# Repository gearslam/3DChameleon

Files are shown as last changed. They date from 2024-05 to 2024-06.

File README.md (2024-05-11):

# 3DChameleon
Klipper direct stepper  control for 3DChameleon

Setup for Ender 3 Max Neo, with Sprite Extruder Pro with K1 Hotend, silicone wipe purge bucket, and BTT SKR3 EZ with BTT_MOT_EXP expansion module.
ysplit_distance is configured for custom y-splitter, 2in1 & 4in1 Splitter by Solidoodle2 on Thingiverse: https://www.thingiverse.com/thing:3490163
distance will need to be increased for original 3DChameleon Y-Splitter.

TOOL_INIT there is a configuration value that needs to be adjusted for proper filament selection.

Purge Bucket for CR-10 with adjustable X-Axis by randyre on Thingiverse: https://www.thingiverse.com/thing:4134504
For K1 or volcano nozzle purge wipe bucket needs to be trimmed down about 6mm using negative parts volume in slicer.

PrusaSlicer Start G-code:
START_PRINT EXTRUDER_TEMP={first_layer_temperature[0]} BED_TEMP={first_layer_bed_temperature[0]}
T{initial_tool}  ;only needed for PrusaSlicer, Orca Slicer, uncheck Manual Filament Change.

Filament Change with purge and wipe just under 7 seconds.

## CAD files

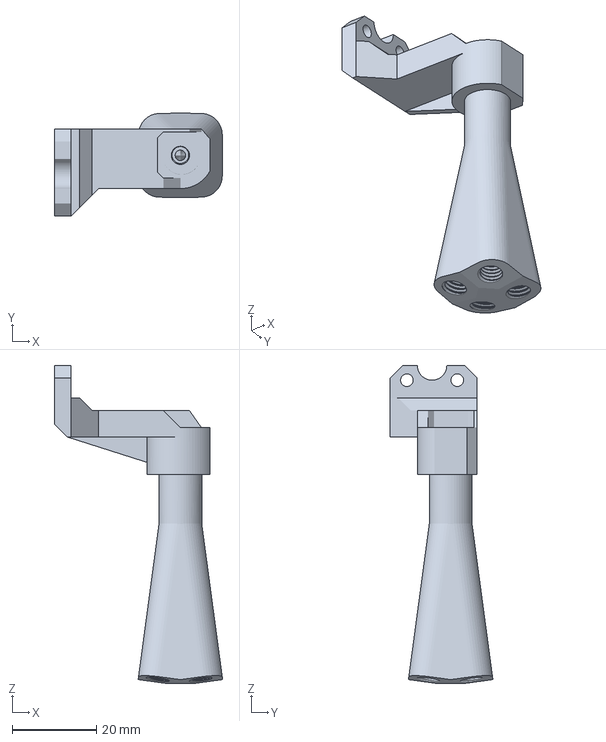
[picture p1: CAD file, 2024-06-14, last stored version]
4in1_thread_modded.3mf
40.1 x 24.5 x 75.7 mm

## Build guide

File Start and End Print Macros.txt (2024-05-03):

# PrusaSlicer Start G-code:
# START_PRINT EXTRUDER_TEMP={first_layer_temperature[0]} BED_TEMP={first_layer_bed_temperature[0]}
# T{initial_tool}

[gcode_macro START_PRINT]
variable_parameter_EXTRUDER_TEMP: 0
variable_parameter_BED_TEMP: 60
gcode:
    # preheat, homing, etc
    BED_MESH_PROFILE LOAD="default"
    M140 S{BED_TEMP}         ; Start bed heating
    G90                      ; Set absolute position
    G92 E0                   ; Reset extruder
    TOOL_INIT                ; Home 3D Chameleon
    M190 S{BED_TEMP}         ; Wait for bed to reach temperature
    M104 S{EXTRUDER_TEMP}    ; Start heating nozzle while Homing
    G28                      ; Home all axes
    G1 Z3.0 X318 F25000.0    ; Move print head to purge bucket
    M109 S{EXTRUDER_TEMP}    ; Set and wait for nozzle to reach temperature
    SET_FILAMENT_SENSOR SENSOR=filament_sensor ENABLE=0    ; Disable filament sensor for 3D Chameleon

[gcode_macro END_PRINT]
gcode:
    {% set TOOL= printer["gcode_macro TOOL_INIT"].tool %}
    M140 S0                  ; Turn off bed heater
    M106 S0                  ; turn off cooling fans
    G91                      ; Set incremental positioning
    G1 Z10                   ; Raise nozzle
    G90                      ; Set absolute positioning
    G1 X318 Y300 F15000      ; Present
    M104 S0                  ; Turn off hotend heater
    EXTRUDER_UNLOAD          ; Remove filament from extruder
    TOOL_SELECT TOOL={TOOL}  ; Select current tool
    CHAMELEON_UNLOAD         ; Backout filament to top of spliter
    TOOL_FREE TOOL={TOOL}    ; Free current tool
    M84                      ; Turn off stepper motors
    SET_FILAMENT_SENSOR SENSOR=filament_sensor ENABLE=1    ; Re-enable filament sensor

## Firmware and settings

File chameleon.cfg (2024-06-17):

[gcode_macro TOOL_INIT]
description: homes the tool selector. Needed before any tool change.
variable_tool: -1
variable_ysplit_distance: 90
gcode:
  MANUAL_STEPPER STEPPER=selector SET_POSITION=0 
  MANUAL_STEPPER STEPPER=selector MOVE=-1.65 SPEED=5
  MANUAL_STEPPER STEPPER=selector SET_POSITION=0 
  MANUAL_STEPPER STEPPER=selector MOVE=0.14 SPEED=5      ; 3D Chameleon Calibration
  MANUAL_STEPPER STEPPER=selector SET_POSITION=0 
  MANUAL_STEPPER STEPPER=chameleon SET_POSITION=0
  # Set the tool to inital load
  SET_GCODE_VARIABLE MACRO=TOOL_INIT VARIABLE=tool VALUE=-1

[gcode_macro WIPE]
gcode:
  G1 X318 F40000       ; Move print head to purge bucket
  G1 X300 F2000        ; Wipe nozzle
  G1 F40000            ; Increase travel speed

[gcode_macro PURGE_WIPE]
gcode:
  G1 X318 F40000       ; Move print head to purge bucket
  G90                  ; Set absolute position
  G92 E0               ; Reset the extruder's origin
  G1 E40 F650          ; Purge 40mm
  G1 X300 F2000        ; Wipe nozzle
  G1 F40000            ; Increase travel speed
  
[gcode_macro TS0]
gcode:
  TOOL_SELECT TOOL=0

[gcode_macro TS1]
gcode:
  TOOL_SELECT TOOL=1

[gcode_macro TS2]
gcode:
  TOOL_SELECT TOOL=2

[gcode_macro TS3]
gcode:
  TOOL_SELECT TOOL=3

[gcode_macro TOOL_SELECT]
gcode:
  {% set TOOL = params.TOOL|int %}
  M117 "Setting tool to TOOL{TOOL}"
  {% if TOOL == 0 %}
    MANUAL_STEPPER stepper=selector MOVE=0
  {% elif TOOL == 1 %}
    MANUAL_STEPPER stepper=selector MOVE=0.5
  {% elif TOOL == 2 %}
    MANUAL_STEPPER stepper=selector MOVE=1.0
  {% elif TOOL == 3 %}
    MANUAL_STEPPER stepper=selector MOVE=1.5
  {% endif %}
  SET_GCODE_VARIABLE MACRO=TOOL_INIT VARIABLE=tool VALUE={TOOL}

[gcode_macro TOOL_FREE]
gcode:
  {% set TOOL = params.TOOL|int %}
  M117 "Free filament path for tool {TOOL}"
  {% if TOOL == 0 %}
    MANUAL_STEPPER stepper=selector MOVE=1 
  {% elif TOOL == 1 %}
    MANUAL_STEPPER stepper=selector MOVE=1.5
  {% elif TOOL == 2 %}
    MANUAL_STEPPER stepper=selector MOVE=0
  {% elif TOOL == 3 %}
    MANUAL_STEPPER stepper=selector MOVE=0.5
  {% endif %}
  
[gcode_macro CHAMELEON_UNLOAD]
description: Unloads the filament from the tubing
gcode:
  {% set TOOL=printer["gcode_macro TOOL_INIT"].tool %}
  {% set YSPLIT_DIST=printer["gcode_macro TOOL_INIT"].ysplit_distance %}
  MANUAL_STEPPER STEPPER=chameleon SET_POSITION=0
  {% if TOOL == -1 or TOOL == 0 or TOOL == 1 %}
  M117 "Move tool {TOOL} by -{YSPLIT_DIST}"
  MANUAL_STEPPER stepper=chameleon MOVE=-{YSPLIT_DIST} SPEED=250 ACCEL=250
  {% else %}
  M117 "Move tool {TOOL} by {YSPLIT_DIST}"
  MANUAL_STEPPER stepper=chameleon MOVE={YSPLIT_DIST} SPEED=250 ACCEL=250
  {% endif %}

[gcode_macro CHAMELEON_LOAD]
description: Loads the filament into the extruder bowden
gcode:
  {% set TOOL=printer["gcode_macro TOOL_INIT"].tool %}
  {% set YSPLIT_DIST=printer["gcode_macro TOOL_INIT"].ysplit_distance %}
  MANUAL_STEPPER STEPPER=chameleon SET_POSITION=0
  {% if TOOL == -1 or TOOL == 0 or TOOL == 1 %}
  M117 "Move tool {TOOL} by {YSPLIT_DIST+2}"
  MANUAL_STEPPER stepper=chameleon MOVE={YSPLIT_DIST+2} SPEED=250 ACCEL=250
  {% else %}
  M117 "Move tool {TOOL} by -{YSPLIT_DIST+2}"
  MANUAL_STEPPER stepper=chameleon MOVE=-{YSPLIT_DIST+2} SPEED=250 ACCEL=250
  {% endif %}

[gcode_macro EXTRUDER_UNLOAD]
description: Unloads the filament from the extruder before a tool change
gcode:
  G90              ; Set absolute position
  G92 E0           ; Reset the extruder's origin
  G1 E-35 F14000   ; Quickly retract filament for cooling
  G4 P2000         ; Dwell for 2.0 seconds
  G1 E-40 F1000    ; Retract filament for cooling
  G4 P1000         ; Dwell for 1.0 seconds
  G1 E-45 F1000    ; Quickly remove filament from extruder

[gcode_macro EXTRUDER_LOAD]
description: Loads the filament in the extruder after a tool change
gcode:
  G90              ; Set absolute position
  G92 E0           ; Reset the extruder's origin
  G1 E40 F3000     ; Load Extruder
  G1 E41 F650      ; Load Extruder
  
[gcode_macro T0]
description: Changes the filament to that loaded in tool 0
gcode:
  # Fetch current tool
  {% set TOOL= printer["gcode_macro TOOL_INIT"].tool %}
  {% set YSPLIT_DIST=printer["gcode_macro TOOL_INIT"].ysplit_distance %}
  {% if TOOL != 0 %}     ; Verify tool not already selected
    G1 X318 F40000       ; Move print head to purge bucket
    {% if TOOL != -1 %}  ; If its inital load; do not unload
      EXTRUDER_UNLOAD
      TOOL_SELECT TOOL={TOOL}
      CHAMELEON_UNLOAD
    {% endif %}
    # Select the new tool 
    {% set TOOL=0 %}
    SET_GCODE_VARIABLE MACRO=TOOL_INIT VARIABLE=tool VALUE=0
    TOOL_SELECT TOOL={TOOL}
    CHAMELEON_LOAD
    # Clear the path for the filament in the selector
    TOOL_FREE TOOL={TOOL}
    EXTRUDER_LOAD
    # Purge and wipe the nozzle
    PURGE_WIPE
  {% endif %}

[gcode_macro T1]
description: Changes the filament to that loaded in tool 1
gcode:
  # Fetch current tool
  {% set TOOL= printer["gcode_macro TOOL_INIT"].tool %}
  {% set YSPLIT_DIST=printer["gcode_macro TOOL_INIT"].ysplit_distance %}
  {% if TOOL != 1 %}     ; Verify tool not already selected
    G1 X318 F40000       ; Move print head to purge bucket
    {% if TOOL != -1 %}  ; If its inital load; do not unload
      EXTRUDER_UNLOAD
      TOOL_SELECT TOOL={TOOL}
      CHAMELEON_UNLOAD
    {% endif %}
    # Select the new tool 
    {% set TOOL=1 %}
    SET_GCODE_VARIABLE MACRO=TOOL_INIT VARIABLE=tool VALUE={TOOL}
    TOOL_SELECT TOOL={TOOL}
    CHAMELEON_LOAD
    # Clear the path for the filament in the selector
    TOOL_FREE TOOL={TOOL}
    EXTRUDER_LOAD
    # Purge and wipe the nozzle
    PURGE_WIPE
  {% endif %}

[gcode_macro T2]
description: Changes the filament to that loaded in tool 2
gcode:
  # Fetch current tool
  {% set TOOL= printer["gcode_macro TOOL_INIT"].tool %}
  {% set YSPLIT_DIST=printer["gcode_macro TOOL_INIT"].ysplit_distance %}
  {% if TOOL != 2 %}     ; Verify tool not already selected
    G1 X318 F40000       ; Move print head to purge bucket
    {% if TOOL != -1 %}  ; If its inital load; do not unload
      EXTRUDER_UNLOAD
      TOOL_SELECT TOOL={TOOL}
      CHAMELEON_UNLOAD
    {% endif %}
    # Select the new tool 
    {% set TOOL=2 %}
    SET_GCODE_VARIABLE MACRO=TOOL_INIT VARIABLE=tool VALUE={TOOL}
    TOOL_SELECT TOOL={TOOL}
    CHAMELEON_LOAD
    # Clear the path for the filament in the selector
    TOOL_FREE TOOL={TOOL}
    EXTRUDER_LOAD
    # Purge and wipe the nozzle
    PURGE_WIPE
 {% endif %}

[gcode_macro T3]
description: Changes the filament to that loaded in tool 2
gcode:
  # Fetch current tool
  {% set TOOL= printer["gcode_macro TOOL_INIT"].tool %}
  {% set YSPLIT_DIST=printer["gcode_macro TOOL_INIT"].ysplit_distance %}
  {% if TOOL != 3 %}     ; Verify tool not already selected
    G1 X318 F40000       ; Move print head to purge bucket
    {% if TOOL != -1 %}  ; If its inital load; do not unload
      EXTRUDER_UNLOAD
      TOOL_SELECT TOOL={TOOL}
      CHAMELEON_UNLOAD
    {% endif %}
    # Select the new tool 
    {% set TOOL=3 %}
    TOOL_SELECT TOOL={TOOL}
    SET_GCODE_VARIABLE MACRO=TOOL_INIT VARIABLE=tool VALUE={TOOL}
    CHAMELEON_LOAD
    # Clear the path for the filament in the selector
    TOOL_FREE TOOL={TOOL}
    EXTRUDER_LOAD
    # Purge and wipe the nozzle
    PURGE_WIPE
  {% endif %}

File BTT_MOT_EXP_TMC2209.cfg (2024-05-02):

# 3D CHAMELEON
[manual_stepper selector]
step_pin: EXP2_6
dir_pin: !EXP2_5
enable_pin: !EXP2_7
microsteps: 16
rotation_distance: 2
velocity: 10

[tmc2209 manual_stepper selector]
uart_pin: EXP1_6
run_current: 1.000
hold_current: 0.500
interpolate: False
stealthchop_threshold: 0
# diag_pin: EXP1_5

[manual_stepper chameleon]
step_pin: EXP2_3
dir_pin: EXP2_4
enable_pin: !EXP1_8
microsteps: 16
rotation_distance: 20

[tmc2209 manual_stepper chameleon]
uart_pin: EXP1_4
run_current: 1.200
hold_current: 0.500
interpolate: False
stealthchop_threshold: 0
# diag_pin: EXP1_3
